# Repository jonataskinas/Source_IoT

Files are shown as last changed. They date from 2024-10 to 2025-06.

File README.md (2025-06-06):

# Source_IoT - V.01.00

Este repositório contém os arquivos de projeto da placa **Source_IoT V.01.00**, utilizada como ferramenta didática no curso **Projeto e Montagem de Placas de Circuito Impresso**.



## Sobre o Curso: Projeto e Montagem de Placas de Circuito Impresso

Este repositório reúne os arquivos do projeto **Source\_IoT - V.01.00**, desenvolvido como parte do curso *Projeto e Montagem de Placas de Circuito Impresso*. O curso tem como objetivo capacitar estudantes no **desenvolvimento, documentação, fabricação e montagem de placas de circuito impresso (PCBs)**.

Dividido em três módulos, o curso oferece uma jornada completa desde as boas práticas iniciais até a montagem física da placa:

### Módulo 1: Boas Práticas em Projetos de PCB

* Levantamento e especificação de requisitos para PCBs.
* Elaboração de representações arquiteturais e organização estrutural do projeto.
* Aplicação de boas práticas no fluxo de execução de projetos eletrônicos.

### Módulo 2: Projeto de uma Placa de Circuito Impresso

* Criação e organização do projeto em ambiente de CAD eletrônico.
* Construção de templates e bibliotecas de componentes.
* Elaboração de esquemáticos, roteamento e layout da PCB.
* Geração dos arquivos de manufatura e documentação final para produção.

### Módulo 3: Treinamento de Soldagem e Montagem

* Técnicas práticas de soldagem SMD e PTH.
* Procedimentos de montagem da placa projetada, garantindo qualidade e funcionalidade no produto final.

## Sobre a Placa: Source\_IoT - V.01.00

A **Source\_IoT - V.01.00** é uma placa didática projetada com foco em aplicações de Internet das Coisas (IoT), cuja ênfase principal está na **gestão de energia confiável a partir de múltiplas fontes de alimentação**, com mecanismos de proteção e suporte a bateria de backup.

A arquitetura da placa é composta por:

### 🔌 Fontes de Alimentação Múltiplas

* Entrada via **USB (5V)**
* Entrada externa via conector **VCC (12–24V)**
* Alimentação por **bateria Li-Ion ICR 14500 (3.7V - 700 mAh)** como fonte de backup

Essas entradas são gerenciadas com proteção contra tensão reversa e reguladas por um conversor buck (**AP63205**) e um conversor buck-boost (**RT6154AGQW**), garantindo estabilidade e segurança no fornecimento de energia para o microcontrolador **Raspberry Pi Pico W**.

### ⚡ Circuitos de Proteção

* **Proteção contra inversão de polaridade** nas entradas externas
* **Circuito de proteção da bateria**, baseado no comparador **TLV7031** e shunt **LM4041**, que monitora limites de tensão mínima e reinício da alimentação para preservar a integridade da célula

### 🔋 Gerenciamento da Carga da Bateria

* Utilização do carregador **MCP73831** (SOT-23-5), capaz de fornecer até **500 mA** para uma célula Li-Ion
* O circuito incorpora resistores de programação e indicadores de status de carga, assegurando operação segura e eficiente

### 🧠 Aplicação Principal

A placa foi concebida para ser integrada a sistemas embarcados com comunicação wireless e sensores externos, tendo como núcleo o **Raspberry Pi Pico W**. Seu objetivo é fornecer uma infraestrutura robusta para prototipagem e testes de soluções IoT com **continuidade de operação mesmo na ausência da fonte principal**.

## Organização dos Arquivos

Os arquivos do projeto estão organizados da seguinte forma:

### 📂 Altium Designer Sources

Na pasta `PCB_Project_Source_IoT` estão todos os arquivos fonte (`.PcbDoc`, `.SchDoc`, etc.) utilizados no design da PCB no Altium Designer.

### 🛠️ Fabrication and Assembly

Na subpasta `Project Outputs for PCB_Project_Source_IoT` (dentro da pasta do projeto `PCB_Project_Source_IoT`) estão os arquivos de fabricação (Gerbers, NC Drill), esquemáticos em PDF, lista de materiais (BOM - *Bill of Materials*) e outras informações essenciais para a fabricação e montagem da PCB.

## Como Utilizar este Repositório

### 📘 Para Estudo

Explore os esquemáticos e o layout da PCB na pasta descrita em **Altium Designer Sources** (requer Altium Designer) ou os PDFs em **Fabrication and Assembly**.

### 🏭 Para Fabricação

Utilize os arquivos da pasta **Fabrication and Assembly** para encomendar a fabricação da placa e adquirir os componentes listados na **BOM**.

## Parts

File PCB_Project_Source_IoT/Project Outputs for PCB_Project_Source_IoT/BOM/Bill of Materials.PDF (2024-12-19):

Projeto:
Arquivo:
Versão:
Data:
Contato:
Item | Quantity | Designator | Manufacturer Part Number | Description | Supplier 1 | Supplier Part Number 1 | Supplier Stock 1 | Supplier Unit Price 1 | Supplier Subtotal 1
1 | 4 | C1, C5, C7, C9 | CL21B104KACNNNC | CAP CER 0.1UF 25V
2 | 2 | C2, C3 | CL21A226MAYNNNE | CAP CER 22UF 25V
3 | 1 | C4 | CL31A106KBHNNNE | CAP CER 10UF 50V
4 | 2 | C6, C8 | C2012X5R1E475K125AB | CAP CER 4.7UF 25V
5 | 1 | CONN1 | TSW-101-07-G-D | CONN HEADER
6 | 5 | D1, D3, D7, D13, D14 | LTST-C170GKT | LED GREEN CLEAR
7 | 2 | D2, D15 | MMSZ5245B-TP | DIODE ZENER 15V
8 | 1 | D4 | SMBJ28CAQ-13-F | TVS DIODE 28VWM
9 | 5 | D5, D6, D10, D11, D12 | MBR120VLSFT1G | DIODE SCHOTTKY
10 | 1 | D8 | SMAJ5.0A-13-F | TVS DIODE 5VWM
11 | 1 | D9 | LTST-C171TBKT | LED BLUE CLEAR
12 | 1 | D16 | SMBJ6.0CA-TR | TVS DIODE 6VWM
13 | 4 | J1, J4, J5, J8 | 5447861 | TERM BLOCK PLUG
14 | 4 | J2, J3, J6, J7 | 5444262 | TERM BLOCK HDR 2POS 90DEG 3.81MM
15 | 1 | L1 | 1255AY-4R7M=P3 | FIXED IND 4.7UH
16 | 2 | R1, R8 | CRGCQ0805F100K | RES 100K OHM 1%
17 | 5 | R2, R6, R10, R14, R15 | CRGCQ0805J470R | RES 470 OHM 5%
18 | 3 | R3, R7, R16 | RC0805FR-0710KL | RES 10K OHM 1%
19 | 1 | R4 | RC0805FR-071KL | RES 1K OHM 1%
20 | 1 | R5 | ERJ-6ENF2001V | RES SMD 2K OHM
21 | 1 | R9 | RC0805FR-071ML | RES 1M OHM 1%
22 | 1 | R11 | RC0805FR-07270KL | RES 270K OHM 1%
23 | 1 | R12 | RC0805FR-0716KL | RES 16K OHM 1%
24 | 1 | R13 | RC0805FR-13330KL | RES 330K OHM 1%
25 | 2 | T1, T4 | DMP4065S-7 | MOSFET P-CH 40V
26 | 1 | T2 | DDTC143ZCA-7-F | TRANS PREBIAS NPN 200MW SOT23-3
27 | 1 | T3 | PJA3415_R1_00001 | MOSFET P-CHANNEL 20V 4A SOT23
28 | 1 | U1 | AP63205WU-7 | IC REGBUCK 5V 2A
29 | 1 | U2 | MCP73831T-2ACI/OT | IC BATT CNTL LI-
30 | 1 | U3 | TLV7031QDBVRQ1 | AUTOMOTIVE NANOPOWER COMPARATOR
31 | 1 | U4 | LM4041DYM3-1.2-TR | IC VREF SHUNT 1%
X7R 0805 | Digikey | 1276-1099-1-ND | 316661 | USD 0,02 | USD 0,15
X5R 0805 | Digikey | 1276-CL21A226MAYNNNECT-ND | 762600 | USD 0,20 | USD 0,40
X5R 1206 | DigiKey | 1276-2876-1-ND | 1075805 | USD 0,26 | USD 0,26
X5R 0805 | Digikey | 445-4116-1-ND | 2067686 | USD 0,27 | USD 0,54
VERT 2POS | Digikey | SAM1028-01-ND | 3311 | USD 0,51 | USD 0,51
SMD | Digikey | 160-1179-1-ND | 634631 | USD 0,24 | USD 1,20
500MW SOD123 | Digikey | MMSZ5245B-TPMSCT-ND | 598438 | USD 0,10 | USD 0,20
45.4VC SMB | Digikey | SMBJ28CAQ-13-FDICT-ND | 70239 | USD 0,29 | USD 0,29
20V 1A SOD123FL | Digikey | MBR120VLSFT1GOSCT-ND | 35869 | USD 0,41 | USD 2,05
9.2VC SMA | Digikey | SMAJ5.0A-E3/61GICT-ND | 377044 | USD 0,22 | USD 0,22
CHIP SMD | Digikey | 160-1645-1-ND | 28721 | USD 0,32 | USD 0,32
10.3VC SMB | Digikey | 497-7454-1-ND | 3849 | USD 0,47 | USD 0,47
2POS STR 3.81MM | Digikey | 277-11343-ND | 112391 | USD 1,34 | USD 5,36
Digikey | 277-11313-ND | 196691 | USD 0,70 | USD 2,80
4A 23 MOHM SMD | Digikey | 587-2969-1-ND | 1742 | USD 0,42 | USD 0,42
1/8W 0805 | Digikey | A129773CT-ND | 237957 | USD 0,10 | USD 0,20
1/8W 0805 | Digikey | A130132CT-ND | 807068 | USD 0,03 | USD 0,27
1/8W 0805 | Digikey | 541-3976-1-ND | 1544810 | USD 0,10 | USD 0,30
1/8W 0805 | Digikey | 311-1.00KCRCT-ND | 1414483 | USD 0,10 | USD 0,10
1%1/8W 0805 | DigiKey | P2.00KCCT-ND | 132054 | USD 0,11 | USD 0,11
1/8W 0805 | Digikey | 311-1.00MCRCT-ND | 192975 | USD 0,10 | USD 0,10
1/8W 0805 | Digikey | P270KCCT-ND | 57015 | USD 0,11 | USD 0,11
1/8W 0805 | Digikey | 311-16.0KCRCT-ND | 149107 | USD 0,10 | USD 0,10
1/8W 0805 | Digikey | 13-RC0805FR-13330KLCT-ND | 22156 | USD 0,10 | USD 0,10
2.4A SOT23 | Digikey | DMP4065S-7DICT-ND | 31505 | USD 0,32 | USD 0,64
Digikey | 1727-3045-1-ND | 11441 | USD 0,10 | USD 0,10
Digikey | 3757-PJA3415_R1_00001CT-ND | 6943 | USD 0,33 | USD 0,33
TSOT23-6 | Digikey | AP63205WU-7DICT-ND | 29947 | USD 1,32 | USD 1,32
ION 1CEL SOT23-5 | Digikey | MCP73831T-2ACI/OTCT-ND | 92319 | USD 0,76 | USD 0,76
Digikey | 296-TLV7031QDBVRQ1CT-ND | 15246 | USD 0,72 | USD 0,72
SOT23-3 | Digikey | 576-2572-1-ND | 39272 | USD 0,36 | USD 0,36

### 59 USD 20,81

# Lista de Materiais

22/11/2024

v.0.1

PCB_Project_Source_IoT.BomDoc

Virtus CC

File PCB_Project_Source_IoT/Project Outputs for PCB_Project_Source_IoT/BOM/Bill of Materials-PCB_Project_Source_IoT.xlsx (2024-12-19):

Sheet: BoM
Lista de Materiais
Projeto: | Virtus CC
Arquivo: | PCB_Project_Source_IoT.BomDoc
Versão: | v.0.1
Data: | 22/11/2024
Contato:
Item | Quantity | Designator | Manufacturer Part Number | Description | Supplier 1 | Supplier Part Number 1 | Supplier Stock 1 | Supplier Unit Price 1 | Supplier Subtotal 1
1 | 4 | C1, C5, C7, C9 | CL21B104KACNNNC | CAP CER 0.1UF 25V X7R 0805 | Digikey | 1276-1099-1-ND | 316661 | USD 0.01 | USD 0.15
2 | 2 | C2, C3 | CL21A226MAYNNNE | CAP CER 22UF 25V X5R 0805 | Digikey | 1276-CL21A226MAYNNNECT-ND | 762600 | USD 0.20 | USD 0.40
3 | 1 | C4 | CL31A106KBHNNNE | CAP CER 10UF 50V X5R 1206 | DigiKey | 1276-2876-1-ND | 1075805 | USD 0.26 | USD 0.26
4 | 2 | C6, C8 | C2012X5R1E475K125AB | CAP CER 4.7UF 25V X5R 0805 | Digikey | 445-4116-1-ND | 2067686 | USD 0.27 | USD 0.54
5 | 1 | CONN1 | TSW-101-07-G-D | CONN HEADER VERT 2POS | Digikey | SAM1028-01-ND | 3311 | USD 0.51 | USD 0.51
6 | 5 | D1, D3, D7, D13, D14 | LTST-C170GKT | LED GREEN CLEAR SMD | Digikey | 160-1179-1-ND | 634631 | USD 0.24 | USD 1.20
7 | 2 | D2, D15 | MMSZ5245B-TP | DIODE ZENER 15V 500MW SOD123 | Digikey | MMSZ5245B-TPMSCT-ND | 598438 | USD 0.10 | USD 0.20
8 | 1 | D4 | SMBJ28CAQ-13-F | TVS DIODE 28VWM 45.4VC SMB | Digikey | SMBJ28CAQ-13-FDICT-ND | 70239 | USD 0.29 | USD 0.29
9 | 5 | D5, D6, D10, D11, D12 | MBR120VLSFT1G | DIODE SCHOTTKY 20V 1A SOD123FL | Digikey | MBR120VLSFT1GOSCT-ND | 35869 | USD 0.41 | USD 2.05
10 | 1 | D8 | SMAJ5.0A-13-F | TVS DIODE 5VWM 9.2VC SMA | Digikey | SMAJ5.0A-E3/61GICT-ND | 377044 | USD 0.22 | USD 0.22
11 | 1 | D9 | LTST-C171TBKT | LED BLUE CLEAR CHIP SMD | Digikey | 160-1645-1-ND | 28721 | USD 0.32 | USD 0.32
12 | 1 | D16 | SMBJ6.0CA-TR | TVS DIODE 6VWM 10.3VC SMB | Digikey | 497-7454-1-ND | 3849 | USD 0.47 | USD 0.47
13 | 4 | J1, J4, J5, J8 | 5447861 | TERM BLOCK PLUG 2POS STR 3.81MM | Digikey | 277-11343-ND | 112391 | USD 1.34 | USD 5.36
14 | 4 | J2, J3, J6, J7 | 5444262 | TERM BLOCK HDR 2POS 90DEG 3.81MM | Digikey | 277-11313-ND | 196691 | USD 0.70 | USD 2.80
15 | 1 | L1 | 1255AY-4R7M=P3 | FIXED IND 4.7UH 4A 23 MOHM SMD | Digikey | 587-2969-1-ND | 1742 | USD 0.42 | USD 0.42
16 | 2 | R1, R8 | CRGCQ0805F100K | RES 100K OHM 1% 1/8W 0805 | Digikey | A129773CT-ND | 237957 | USD 0.10 | USD 0.20
17 | 5 | R2, R6, R10, R14, R15 | CRGCQ0805J470R | RES 470 OHM 5% 1/8W 0805 | Digikey | A130132CT-ND | 807068 | USD 0.03 | USD 0.27
18 | 3 | R3, R7, R16 | RC0805FR-0710KL | RES 10K OHM 1% 1/8W 0805 | Digikey | 541-3976-1-ND | 1544810 | USD 0.10 | USD 0.30
19 | 1 | R4 | RC0805FR-071KL | RES 1K OHM 1% 1/8W 0805 | Digikey | 311-1.00KCRCT-ND | 1414483 | USD 0.10 | USD 0.10
20 | 1 | R5 | ERJ-6ENF2001V | RES SMD 2K OHM 1% 1/8W 0805 | DigiKey | P2.00KCCT-ND | 132054 | USD 0.11 | USD 0.11
21 | 1 | R9 | RC0805FR-071ML | RES 1M OHM 1% 1/8W 0805 | Digikey | 311-1.00MCRCT-ND | 192975 | USD 0.10 | USD 0.10
22 | 1 | R11 | RC0805FR-07270KL | RES 270K OHM 1% 1/8W 0805 | Digikey | P270KCCT-ND | 57015 | USD 0.11 | USD 0.11
23 | 1 | R12 | RC0805FR-0716KL | RES 16K OHM 1% 1/8W 0805 | Digikey | 311-16.0KCRCT-ND | 149107 | USD 0.10 | USD 0.10
24 | 1 | R13 | RC0805FR-13330KL | RES 330K OHM 1% 1/8W 0805 | Digikey | 13-RC0805FR-13330KLCT-ND | 22156 | USD 0.10 | USD 0.10
25 | 2 | T1, T4 | DMP4065S-7 | MOSFET P-CH 40V 2.4A SOT23 | Digikey | DMP4065S-7DICT-ND | 31505 | USD 0.32 | USD 0.64
26 | 1 | T2 | DDTC143ZCA-7-F | TRANS PREBIAS NPN 200MW SOT23-3 | Digikey | 1727-3045-1-ND | 11441 | USD 0.10 | USD 0.10
27 | 1 | T3 | PJA3415_R1_00001 | MOSFET P-CHANNEL 20V 4A SOT23 | Digikey | 3757-PJA3415_R1_00001CT-ND | 6943 | USD 0.33 | USD 0.33
28 | 1 | U1 | AP63205WU-7 | IC REG BUCK 5V 2A TSOT23-6 | Digikey | AP63205WU-7DICT-ND | 29947 | USD 1.32 | USD 1.32
29 | 1 | U2 | MCP73831T-2ACI/OT | IC BATT CNTL LI-ION 1CEL SOT23-5 | Digikey | MCP73831T-2ACI/OTCT-ND | 92319 | USD 0.76 | USD 0.76
30 | 1 | U3 | TLV7031QDBVRQ1 | AUTOMOTIVE NANO POWER COMPARATOR | Digikey | 296-TLV7031QDBVRQ1CT-ND | 15246 | USD 0.72 | USD 0.72
31 | 1 | U4 | LM4041DYM3-1.2-TR | IC VREF SHUNT 1% SOT23-3 | Digikey | 576-2572-1-ND | 39272 | USD 0.36 | USD 0.36
 | 59 |  |  |  |  |  |  |  | USD 20.81

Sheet: Impostos
Impostos
 | Valores
 | Valor (USD) | Valor (BRL)
Valor do produto | USD 20.81 | BRL 117.30
Valor do frete | USD 40.00 | BRL 225.47
Imposto alfandegário (60%) | USD 36.49 | BRL 205.66
ICMS Paraíba (18%) | USD 21.36 | BRL 120.39
Taxa de Desembaraço FEDEX | USD 16.87 | BRL 95.09
Total | USD 74.71 | BRL 421.15
Valor a Pagar
USD <-> BRL (22/11/24) | 5.42
Spread do dólar (4%) | 5.64
 | Valores
Pagamento 01 | USD 60.81 | BRL 342.77
Pagamento 02 | USD 74.71 | BRL 421.15
Valor total da compra | USD 135.52 | BRL 763.92
Pagamento 01 é realizado no ato da compra, cobrado imediatamente no cartão de crédito.
Pagamento 02 é realizado no ato da recepção da mercadoria, cobrado pelo courrier referente às despesas aduaneiras e de desembaraço.

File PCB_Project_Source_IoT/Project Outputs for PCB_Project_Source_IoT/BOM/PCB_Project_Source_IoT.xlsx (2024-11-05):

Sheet: BoM
Lista de Materiais
Projeto: | Virtus CC
Arquivo: | PCB_Project_Source_IoT.BomDoc
Versão: | v.0.1
Data: | 17/10/2024
Contato:
Item | Quantity | Designator | Manufacturer Part Number | Description | Supplier 1 | Supplier Part Number 1 | Supplier Stock 1 | Supplier Unit Price 1 | Supplier Subtotal 1
1 | 4 | C1, C5, C7, C9 | CL21B104KACNNNC | CAP CER 0.1UF 25V X7R 0805 | Digikey | 1276-1099-1-ND | 264937 | USD 0.03 | USD 0.31
2 | 2 | C2, C3 | CL21A226MAYNNNE | CAP CER 22UF 25V X5R 0805 | Digikey | 1276-CL21A226MAYNNNECT-ND | 307548 | USD 0.26 | USD 0.52
3 | 1 | C4 | CL31A106KBHNNNE | CAP CER 10UF 50V X5R 1206 | DigiKey | 1276-2876-1-ND | 1144400 | USD 0.36 | USD 0.36
4 | 2 | C6, C8 | C2012X5R1E475K125AB | CAP CER 4.7UF 25V X5R 0805 | Digikey | 445-4116-1-ND | 2079251 | USD 0.27 | USD 0.54
5 | 1 | CONN1 | TSW-101-07-G-D | CONN HEADER VERT 2POS | Digikey | SAM1028-01-ND | 1995 | USD 0.30 | USD 0.30
6 | 5 | D1, D3, D7, D13, D14 | LTST-C170GKT | LED GREEN CLEAR SMD | Digikey | 160-1179-1-ND | 683154 | USD 0.24 | USD 1.20
7 | 2 | D2, D15 | MMSZ5245B-TP | DIODE ZENER 15V 500MW SOD123 | Digikey | MMSZ5245B-TPMSCT-ND | 603045 | USD 0.10 | USD 0.20
8 | 1 | D4 | SMBJ28CAQ-13-F | TVS DIODE 28VWM 45.4VC SMB | Digikey | SMBJ28CAQ-13-FDICT-ND | 70506 | USD 0.49 | USD 0.49
9 | 5 | D5, D6, D10, D11, D12 | MBR120VLSFT1G | DIODE SCHOTTKY 20V 1A SOD123FL | Digikey | MBR120VLSFT1GOSCT-ND | 7907 | USD 0.41 | USD 2.05
10 | 1 | D8 | SMAJ5.0A-13-F | TVS DIODE 5VWM 9.2VC SMA | Digikey | SMAJ5.0A-E3/61GICT-ND | 375312 | USD 0.32 | USD 0.32
11 | 1 | D9 | LTST-C171TBKT | LED BLUE CLEAR CHIP SMD | Digikey | 160-1645-1-ND | 37476 | USD 0.32 | USD 0.32
12 | 1 | D16 | SMBJ6.0CA-TR | TVS DIODE 6VWM 10.3VC SMB | Digikey | 497-7454-1-ND | 7168 | USD 0.47 | USD 0.47
13 | 4 | J1, J4, J5, J8 | 5447861 | TERM BLOCK PLUG 2POS STR 3.81MM | Digikey | 277-11343-ND | 112737 | USD 1.34 | USD 5.36
14 | 4 | J2, J3, J6, J7 | 5444262 | TERM BLOCK HDR 2POS 90DEG 3.81MM | Digikey | 277-11313-ND | 197979 | USD 0.70 | USD 2.80
15 | 1 | L1 | 1255AY-4R7M=P3 | FIXED IND 4.7UH 4A 23 MOHM SMD | Digikey | 587-2969-1-ND | 7939 | USD 0.42 | USD 0.42
16 | 2 | R1, R8 | CRGCQ0805F100K | RES 100K OHM 1% 1/8W 0805 | Digikey | A129773CT-ND | 238397 | USD 0.10 | USD 0.20
17 | 5 | R2, R6, R10, R14, R15 | CRGCQ0805J470R | RES 470 OHM 5% 1/8W 0805 | Digikey | A130132CT-ND | 816282 | USD 0.03 | USD 0.27
18 | 3 | R3, R7, R16 | RC0805FR-0710KL | RES 10K OHM 1% 1/8W 0805 | Digikey | 311-10.0KCRCT-ND | 212921 | USD 0.02 | USD 0.17
19 | 1 | R4 | RC0805FR-071KL | RES 1K OHM 1% 1/8W 0805 | Digikey | 311-1.00KCRCT-ND | 1656654 | USD 0.10 | USD 0.10
20 | 1 | R5 | ERJ-6ENF2001V | RES SMD 2K OHM 1% 1/8W 0805 | Digikey | P2.00KCCT-ND | 164204 | USD 0.11 | USD 0.11
21 | 1 | R9 | RC0805FR-071ML | RES 1M OHM 1% 1/8W 0805 | Digikey | 311-1.00MCRCT-ND | 150822 | USD 0.10 | USD 0.10
22 | 1 | R11 | RC0805FR-07270KL | RES 270K OHM 1% 1/8W 0805 | Digikey | 311-270KCRCT-ND | 1252 | USD 0.10 | USD 0.10
23 | 1 | R12 | RC0805FR-0716KL | RES 16K OHM 1% 1/8W 0805 | Digikey | 311-16.0KCRCT-ND | 156943 | USD 0.10 | USD 0.10
24 | 1 | R13 | RC0805FR-13330KL | RES 330K OHM 1% 1/8W 0805 | Digikey | 13-RC0805FR-13330KLCT-ND | 22171 | USD 0.10 | USD 0.10
25 | 2 | T1, T4 | DMP4065S-7 | MOSFET P-CH 40V 2.4A SOT23 | Digikey | DMP4065S-7DICT-ND | 35173 | USD 0.32 | USD 0.64
26 | 1 | T2 | DDTC143ZCA-7-F | TRANS PREBIAS NPN 200MW SOT23-3 | Digikey | 1727-3045-1-ND | 181541 | USD 0.10 | USD 0.10
27 | 1 | T3 | PJA3415_R1_00001 | MOSFET P-CHANNEL 20V 4A SOT23 | Digikey | 3757-PJA3415_R1_00001CT-ND | 6968 | USD 0.23 | USD 0.23
28 | 1 | U1 | AP63205WU-7 | IC REG BUCK 5V 2A TSOT23-6 | Digikey | AP63205WU-7DICT-ND | 19687 | USD 1.32 | USD 1.32
29 | 1 | U2 | MCP73831T-2ACI/OT | IC BATT CNTL LI-ION 1CEL SOT23-5 | Digikey | MCP73831T-2ACI/OTCT-ND | 98382 | USD 0.76 | USD 0.76
30 | 1 | U3 | TLV7031QDBVRQ1 | AUTOMOTIVE NANO POWER COMPARATOR | Digikey | 296-TLV7031QDBVRQ1CT-ND | 15558 | USD 0.82 | USD 0.82
31 | 1 | U4 | LM4041DYM3-1.2-TR | IC VREF SHUNT 1% SOT23-3 | Digikey | 576-2572-1-ND | 40315 | USD 0.36 | USD 0.36
 | 59 |  |  |  |  |  |  |  | USD 21.14

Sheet: Impostos
Impostos
 | Valores
 | Valor (USD) | Valor (BRL)
Valor do produto | USD 21.14 | BRL 119.16
Valor do frete | USD 40.00 | BRL 225.47
Imposto alfandegário (60%) | USD 36.68 | BRL 206.78
ICMS Paraíba (18%) | USD 21.47 | BRL 121.04
Taxa de Desembaraço FEDEX | USD 16.87 | BRL 95.09
Total | USD 75.03 | BRL 422.92
Valor a Pagar
USD <-> BRL (17/10/24) | 5.42
Spread do dólar (4%) | 5.64
 | Valores
Pagamento 01 | USD 61.14 | BRL 344.63
Pagamento 02 | USD 75.03 | BRL 422.92
Valor total da compra | USD 136.17 | BRL 767.55
Pagamento 01 é realizado no ato da compra, cobrado imediatamente no cartão de crédito.
Pagamento 02 é realizado no ato da recepção da mercadoria, cobrado pelo courrier referente às despesas aduaneiras e de desembaraço.

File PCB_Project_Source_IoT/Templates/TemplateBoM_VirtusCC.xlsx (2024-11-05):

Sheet: BoM
Lista de Materiais
Projeto: | Field = Projeto
Arquivo: | Field = DataSourceFileName
Versão: | Field = Rev
Data: | Field = ReportDate
Contato:
Item | Column=Quantity | Column=Designator | Column=Manufacturer Part Number | Column=Description | Column=Supplier 1 | Column=Supplier Part Number 1 | Column=Supplier Stock 1 | Column=Supplier Unit Price 1 | Column=Supplier Subtotal 1
1
2
3
 | 0 |  |  |  |  |  |  |  | USD 0.00

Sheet: Impostos
Impostos
 | Valores
 | Valor (USD) | Valor (BRL)
Valor do produto | USD 0.00 | BRL 0.00
Valor do frete | USD 40.00 | BRL 225.47
Imposto alfandegário (60%) | USD 24.00 | BRL 135.28
ICMS Paraíba (18%) | USD 14.05 | BRL 79.19
Taxa de Desembaraço FEDEX | USD 16.87 | BRL 95.09
Total | USD 54.92 | BRL 309.57
Valor a Pagar
USD <-> BRL (06/10/24) | 5.42
Spread do dólar (4%) | 5.64
 | Valores
Pagamento 01 | USD 40.00 | BRL 225.47
Pagamento 02 | USD 54.92 | BRL 309.57
Valor total da compra | USD 94.92 | BRL 535.04
Pagamento 01 é realizado no ato da compra, cobrado imediatamente no cartão de crédito.
Pagamento 02 é realizado no ato da recepção da mercadoria, cobrado pelo courrier referente às despesas aduaneiras e de desembaraço.

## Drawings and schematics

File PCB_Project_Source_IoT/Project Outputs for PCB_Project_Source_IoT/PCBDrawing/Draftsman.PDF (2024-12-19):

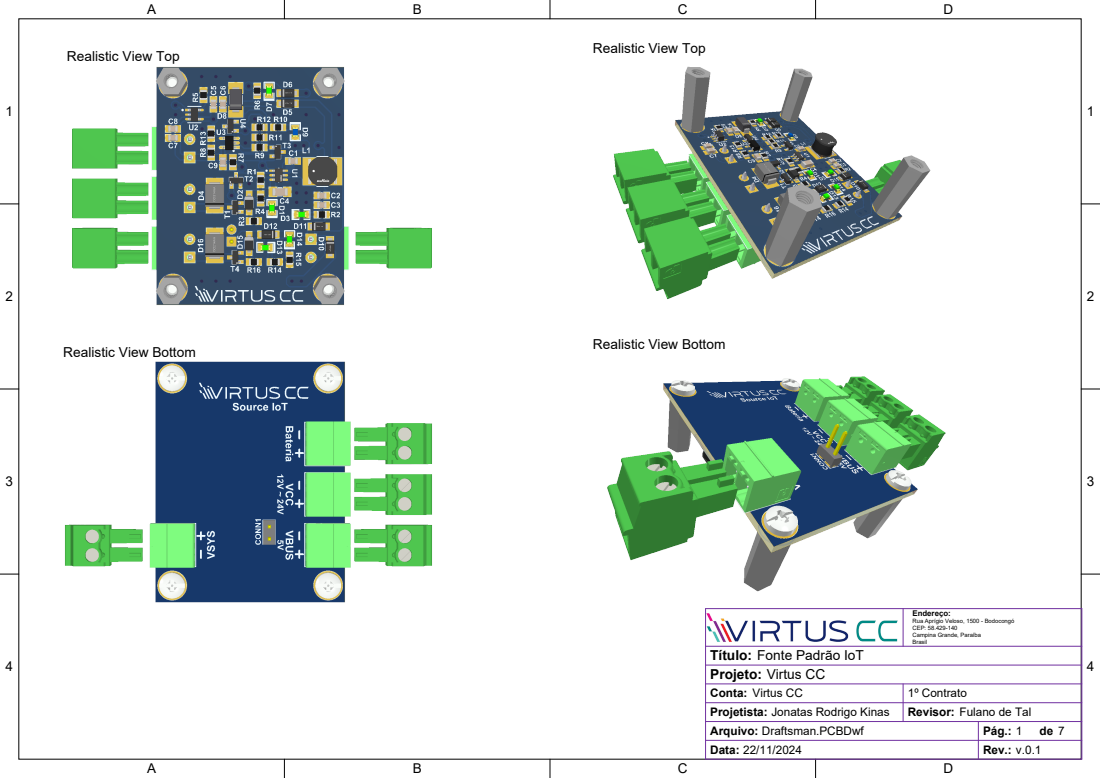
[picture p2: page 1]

Endereço:
Rua Aprígio Veloso, 1500 - Bodocongó
CEP: 58.429-140
Campina Grande, Paraíba
Brasil

Conta: Virtus CC | 1º Contrato
Projetista: Jonatas Rodrigo Kinas | Revisor: Fulano de Tal
Arquivo: Draftsman.PCBDwf | Pág.: de
Data: | Rev.: v.0.1

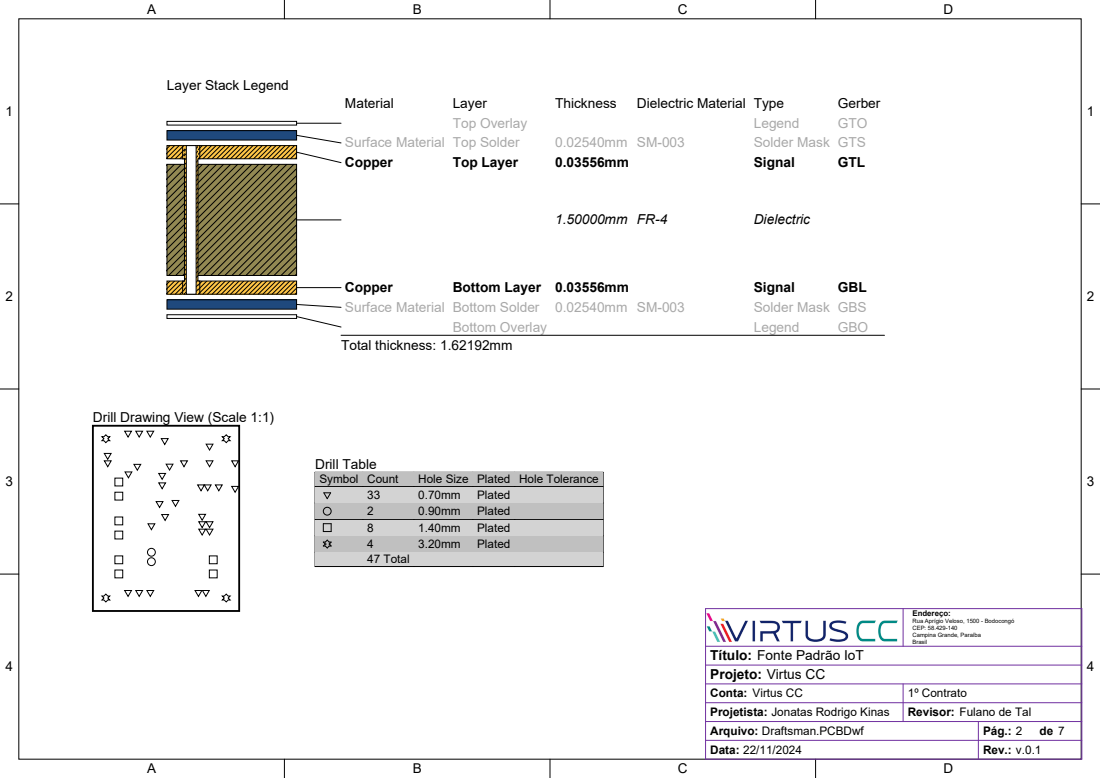
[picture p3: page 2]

Drill Drawing View (Scale 1:1)

Symbol | Count | Hole Size | Plated | Hole Tolerance

33 | 0.70mm | Plated
2 | 0.90mm | Plated
8 | 1.40mm | Plated
4 | 3.20mm | Plated
47 Total

Endereço:
Rua Aprígio Veloso, 1500 - Bodocongó
CEP: 58.429-140
Campina Grande, Paraíba
Brasil

Conta: Virtus CC | 1º Contrato
Projetista: Jonatas Rodrigo Kinas | Revisor: Fulano de Tal

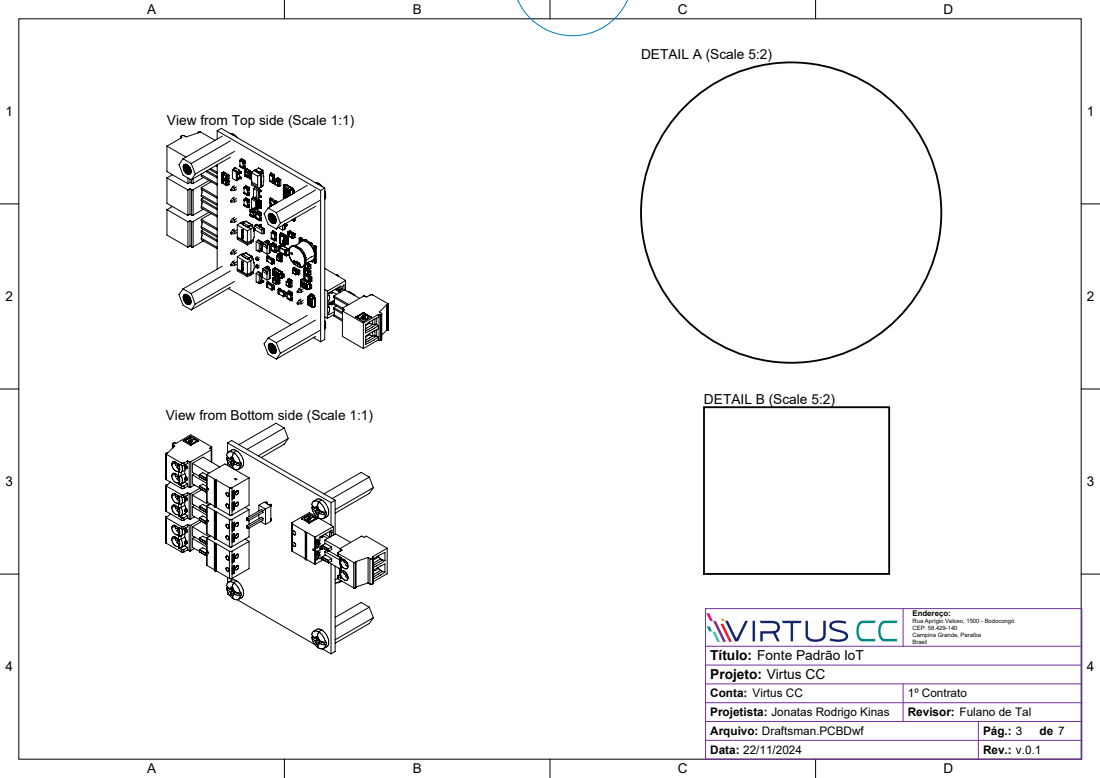
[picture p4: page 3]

View from Top side (Scale 1:1)

View from Bottom side (Scale 1:1)

Endereço:
Rua Aprígio Veloso, 1500 - Bodocongó
CEP: 58.429-140
Campina Grande, Paraíba
Brasil

Conta: Virtus CC | 1º Contrato
Projetista: Jonatas Rodrigo Kinas | Revisor: Fulano de Tal

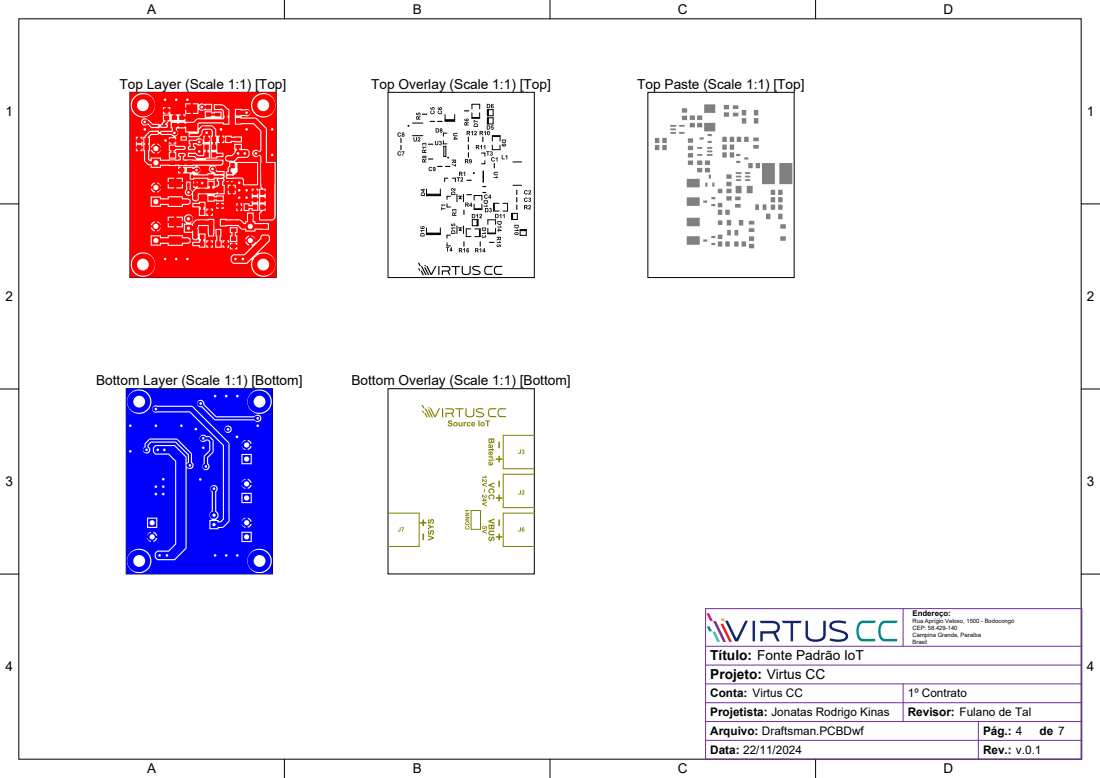
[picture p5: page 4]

Top Layer (Scale 1:1) [Top]

Top Overlay (Scale 1:1) [Top]

Top Paste (Scale 1:1) [Top]

Bottom Layer (Scale 1:1) [Bottom]

Bottom Overlay (Scale 1:1) [Bottom]

Endereço:
Rua Aprígio Veloso, 1500 - Bodocongó
CEP: 58.429-140
Campina Grande, Paraíba
Brasil

Conta: Virtus CC | 1º Contrato
Projetista: Jonatas Rodrigo Kinas | Revisor: Fulano de Tal

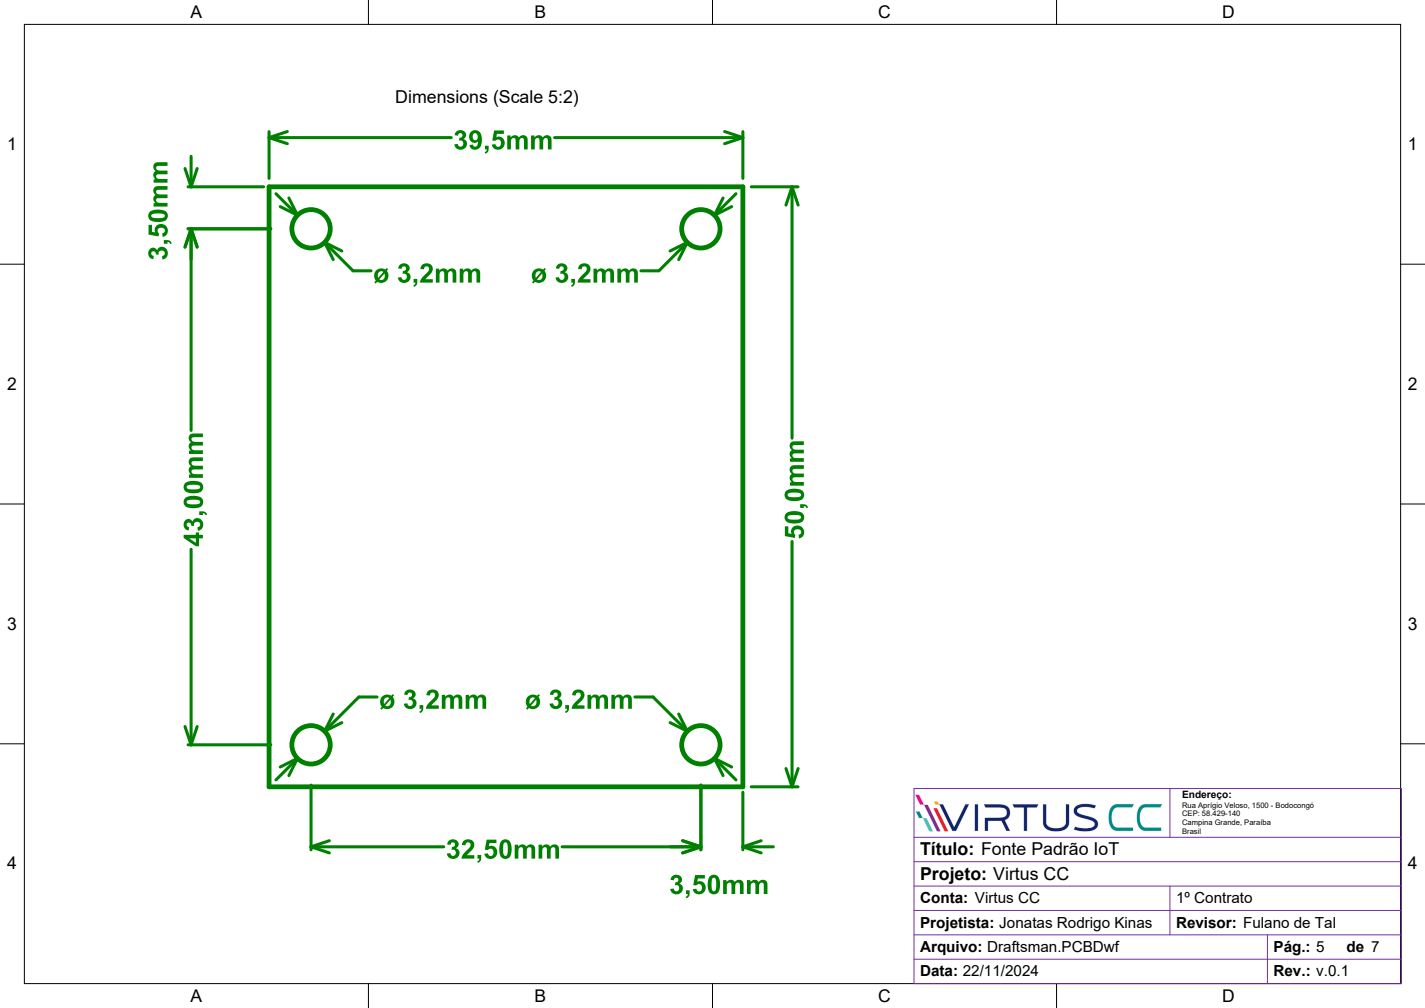
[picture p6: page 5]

Endereço:
Rua Aprígio Veloso, 1500 - Bodocongó
CEP: 58.429-140
Campina Grande, Paraíba
Brasil

Conta: Virtus CC | 1º Contrato
Projetista: Jonatas Rodrigo Kinas | Revisor: Fulano de Tal

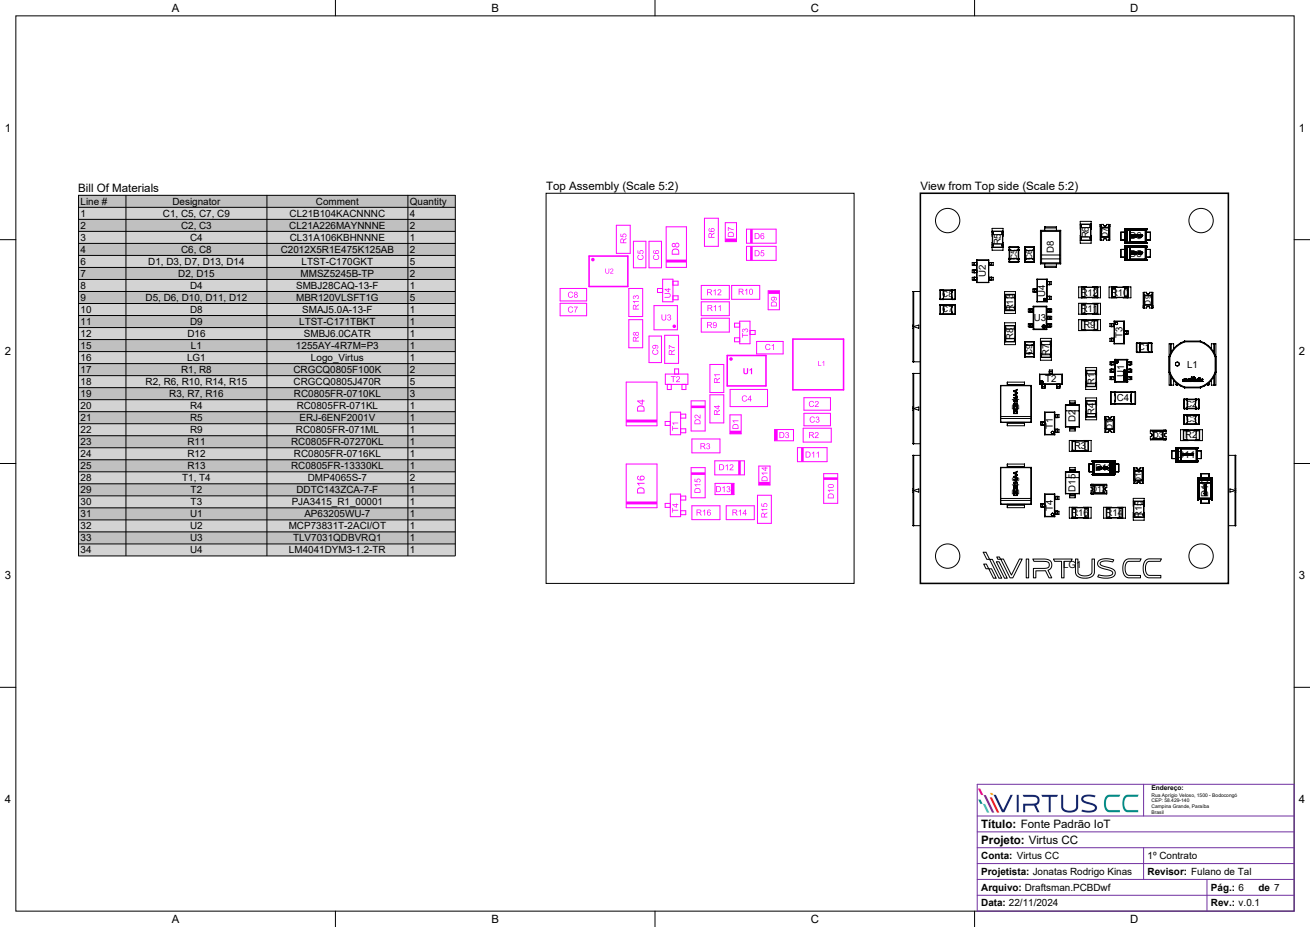
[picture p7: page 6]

1 | C1, C5, C7, C9 | CL21B104KACNNNC | 4
2 | C2, C3 | CL21A226MAYNNNE | 2
3 | C4 | CL31A106KBHNNNE | 1
4 | C6, C8 | C2012X5R1E475K125AB | 2
6 | D1, D3, D7, D13, D14 | LTST-C170GKT | 5
7 | D2, D15 | MMSZ5245B-TP | 2
8 | D4 | SMBJ28CAQ-13-F | 1
9 | D5, D6, D10, D11, D12 | MBR120VLSFT1G | 5

11 | D9 | LTST-C171TBKT | 1
12 | D16 | SMBJ6.0CATR | 1
15 | L1 | 1255AY-4R7M=P3 | 1
16 | LG1 | Logo_Virtus | 1
17 | R1, R8 | CRGCQ0805F100K | 2
18 | R2, R6, R10, R14, R15 | CRGCQ0805J470R | 5
19 | R3, R7, R16 | RC0805FR-0710KL | 3
20 | R4 | RC0805FR-071KL | 1
21 | R5 | ERJ-6ENF2001V | 1
22 | R9 | RC0805FR-071ML | 1
23 | R11 | RC0805FR-07270KL | 1
24 | R12 | RC0805FR-0716KL | 1
25 | R13 | RC0805FR-13330KL | 1
28 | T1, T4 | DMP4065S-7 | 2
29 | T2 | DDTC143ZCA-7-F | 1
30 | T3 | PJA3415_R1_00001 | 1

33 | U3 | TLV7031QDBVRQ1 | 1
34 | U4 | LM4041DYM3-1.2-TR | 1

Endereço:
Rua Aprígio Veloso, 1500 - Bodocongó
CEP: 58.429-140
Campina Grande, Paraíba
Brasil

Conta: Virtus CC | 1º Contrato
Projetista: Jonatas Rodrigo Kinas | Revisor: Fulano de Tal

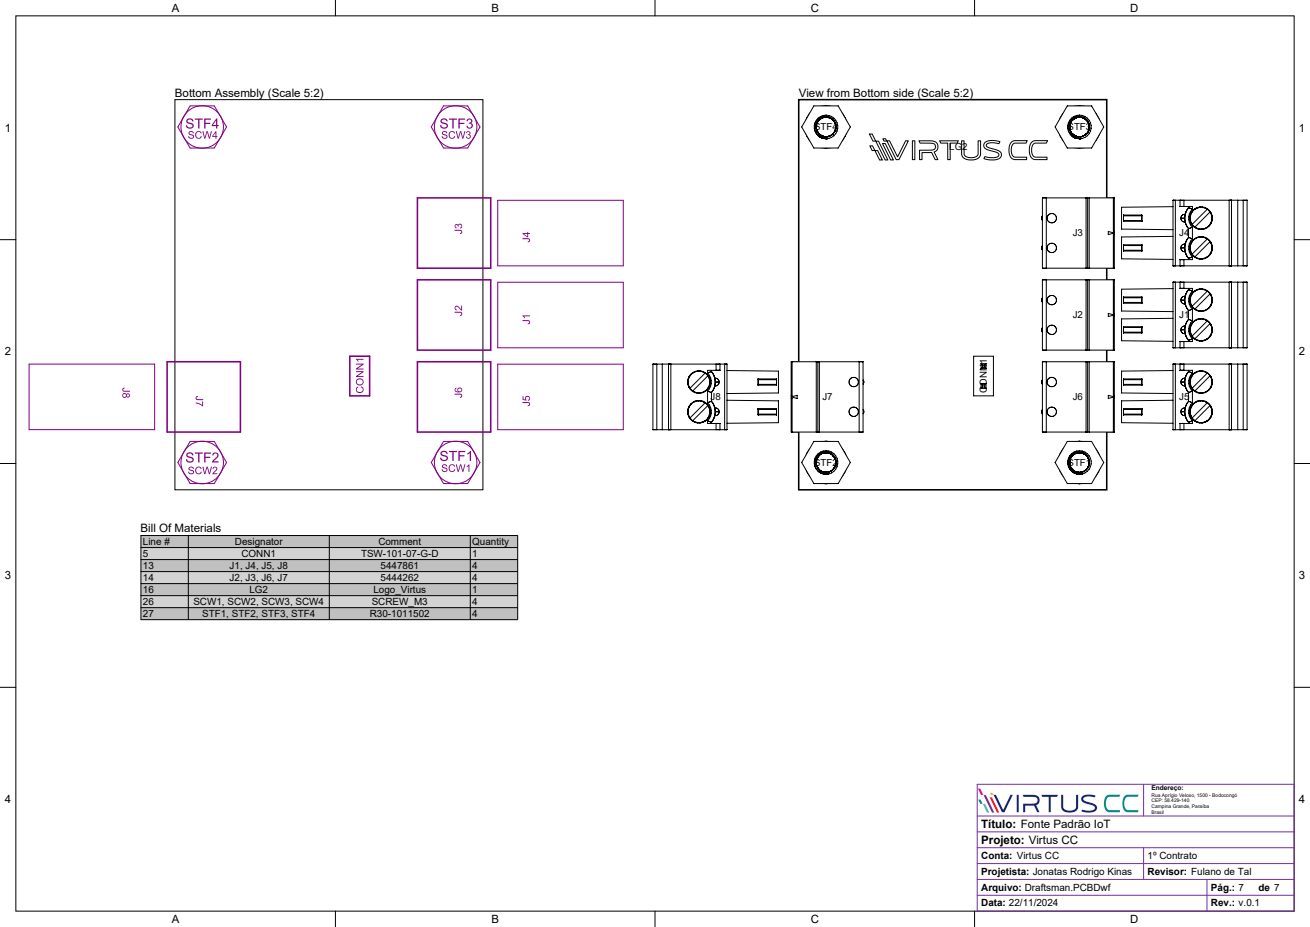
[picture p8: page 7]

View from Bottom side (Scale 5:2)

Line # | Designator | Comment | Quantity
5 | CONN1 | TSW-101-07-G-D | 1
13 | J1, J4, J5, J8 | 5447861 | 4
14 | J2, J3, J6, J7 | 5444262 | 4
16 | LG2 | Logo_Virtus | 1
26 | SCW1, SCW2, SCW3, SCW4 | SCREW_M3 | 4
27 | STF1, STF2, STF3, STF4 | R30-1011502 | 4

Endereço:
Rua Aprígio Veloso, 1500 - Bodocongó
CEP: 58.429-140
Campina Grande, Paraíba
Brasil

Conta: Virtus CC | 1º Contrato
Projetista: Jonatas Rodrigo Kinas | Revisor: Fulano de Tal

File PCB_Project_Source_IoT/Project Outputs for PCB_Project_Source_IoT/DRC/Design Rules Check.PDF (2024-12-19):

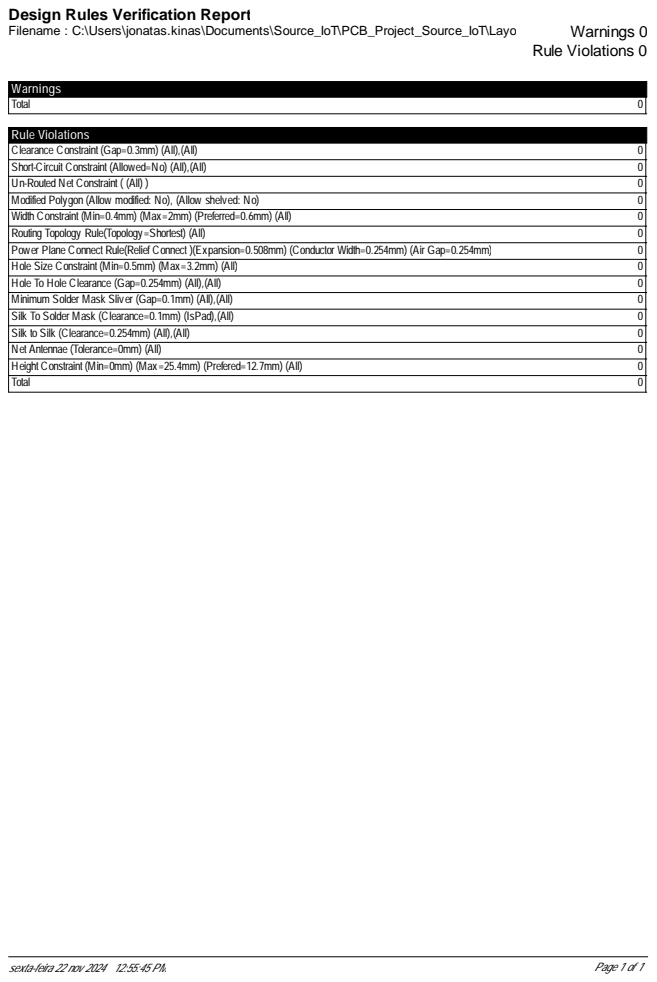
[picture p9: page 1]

Design Rules Verification Report

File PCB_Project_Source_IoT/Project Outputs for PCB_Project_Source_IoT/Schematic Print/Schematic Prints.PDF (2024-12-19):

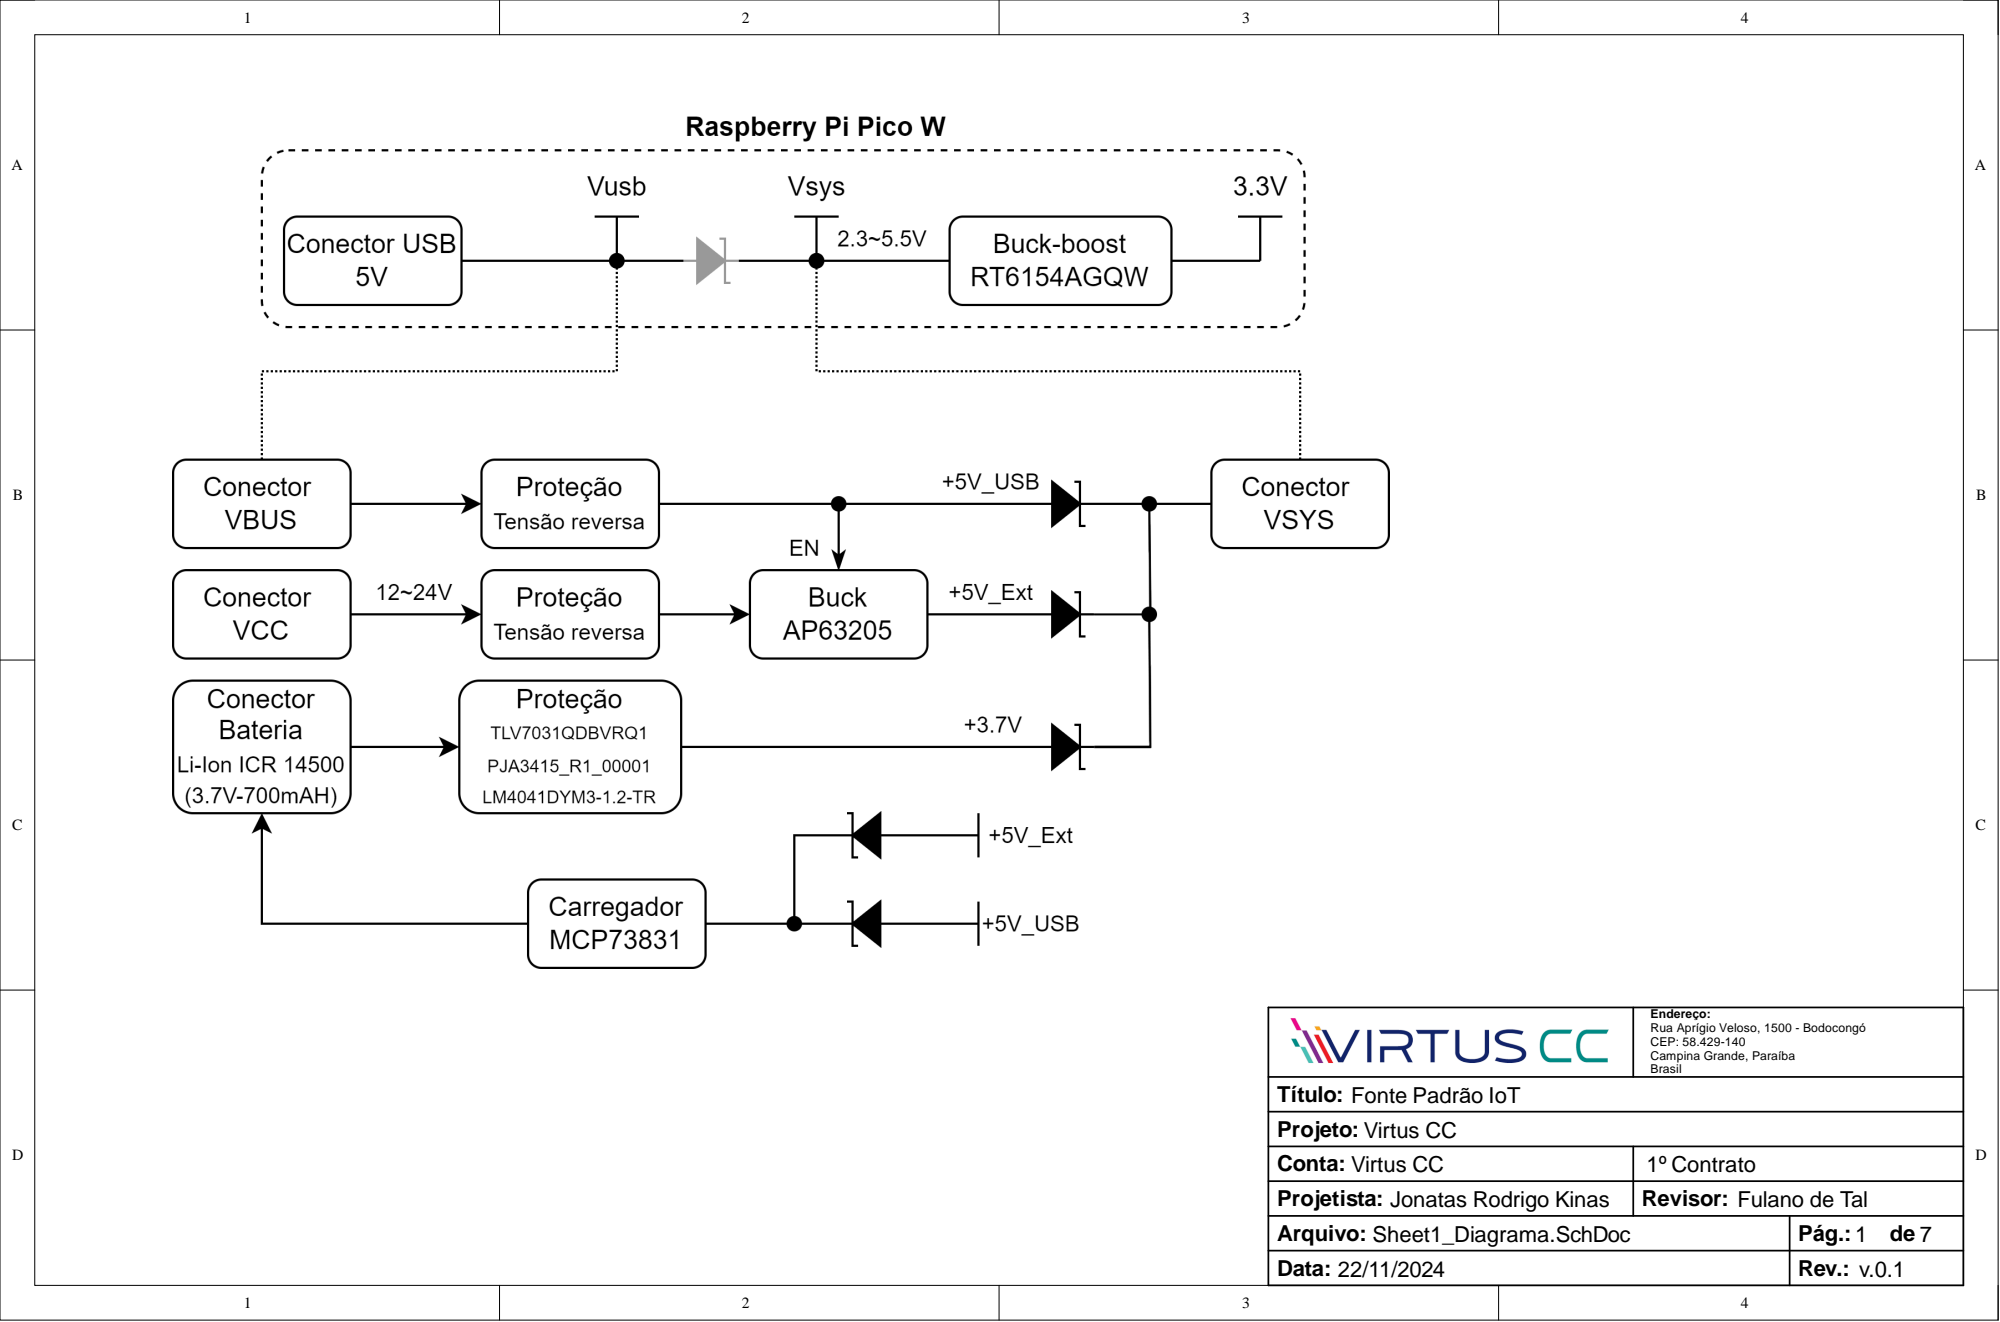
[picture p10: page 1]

Endereço:
Rua Aprígio Veloso, 1500 - Bodocongó
CEP: 58.429-140
Campina Grande, Paraíba
Brasil

Conta: Virtus CC | 1º Contrato
Projetista: Jonatas Rodrigo Kinas | Revisor: Fulano de Tal
Arquivo: Sheet1_Diagrama.SchDoc | Pág.: 1 de 7
Data: 22/11/2024 | Rev.: v.0.1

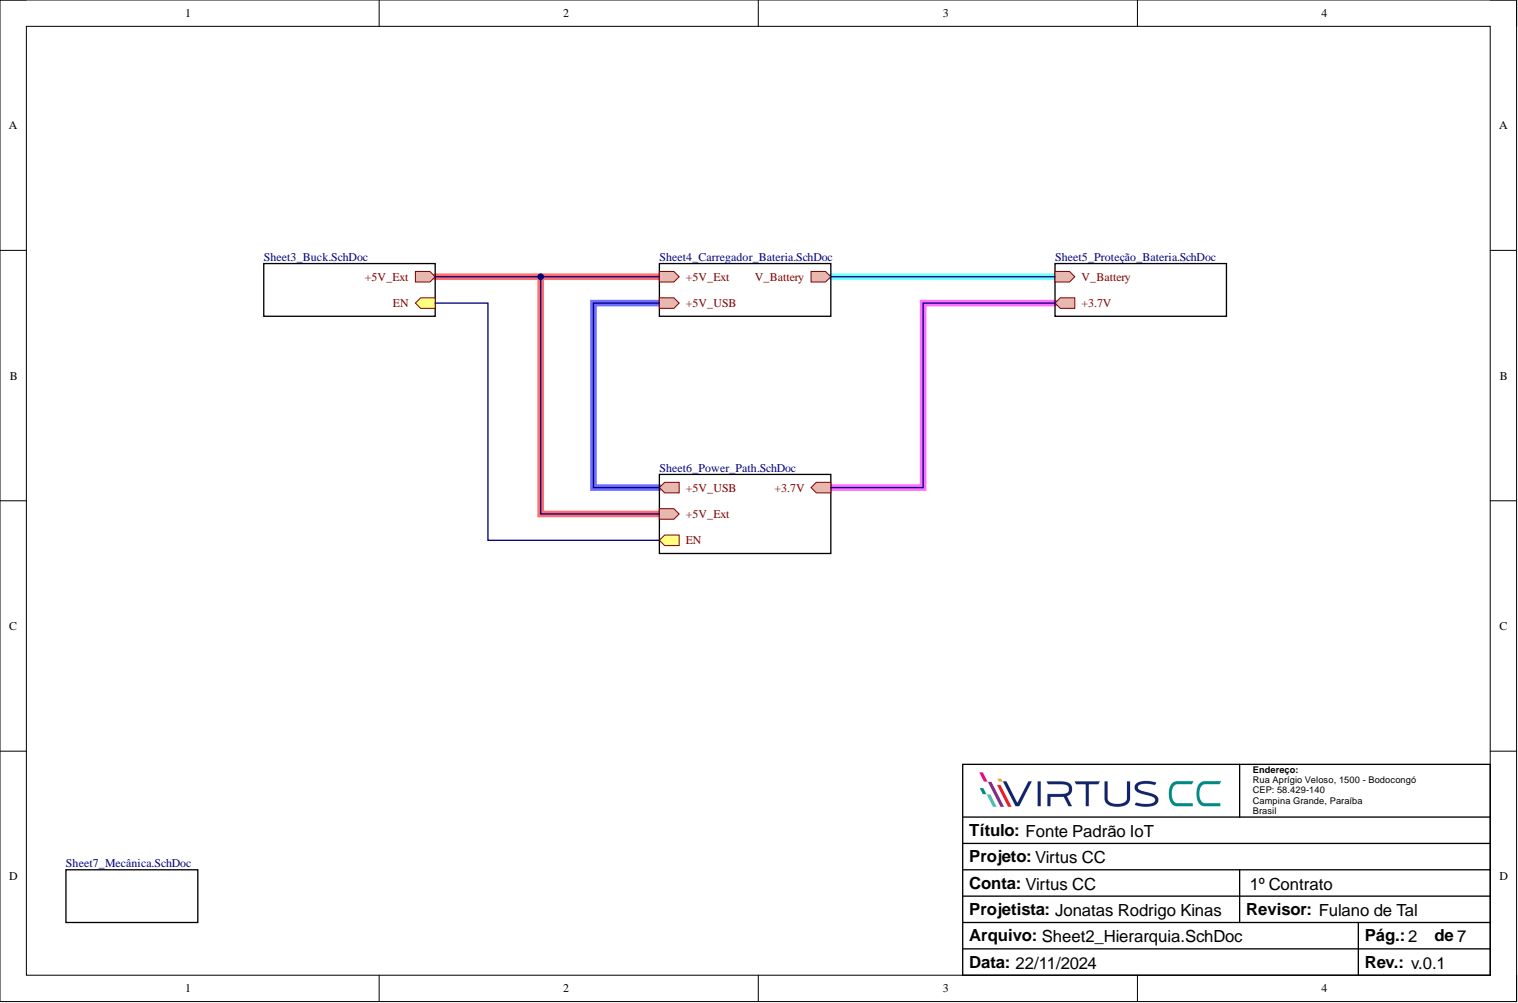
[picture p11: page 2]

Endereço:
Rua Aprígio Veloso, 1500 - Bodocongó
CEP: 58.429-140
Campina Grande, Paraíba
Brasil

Conta: Virtus CC | 1º Contrato
Projetista: Jonatas Rodrigo Kinas | Revisor: Fulano de Tal

Sheet2_Hierarquia.SchDoc | 2 7

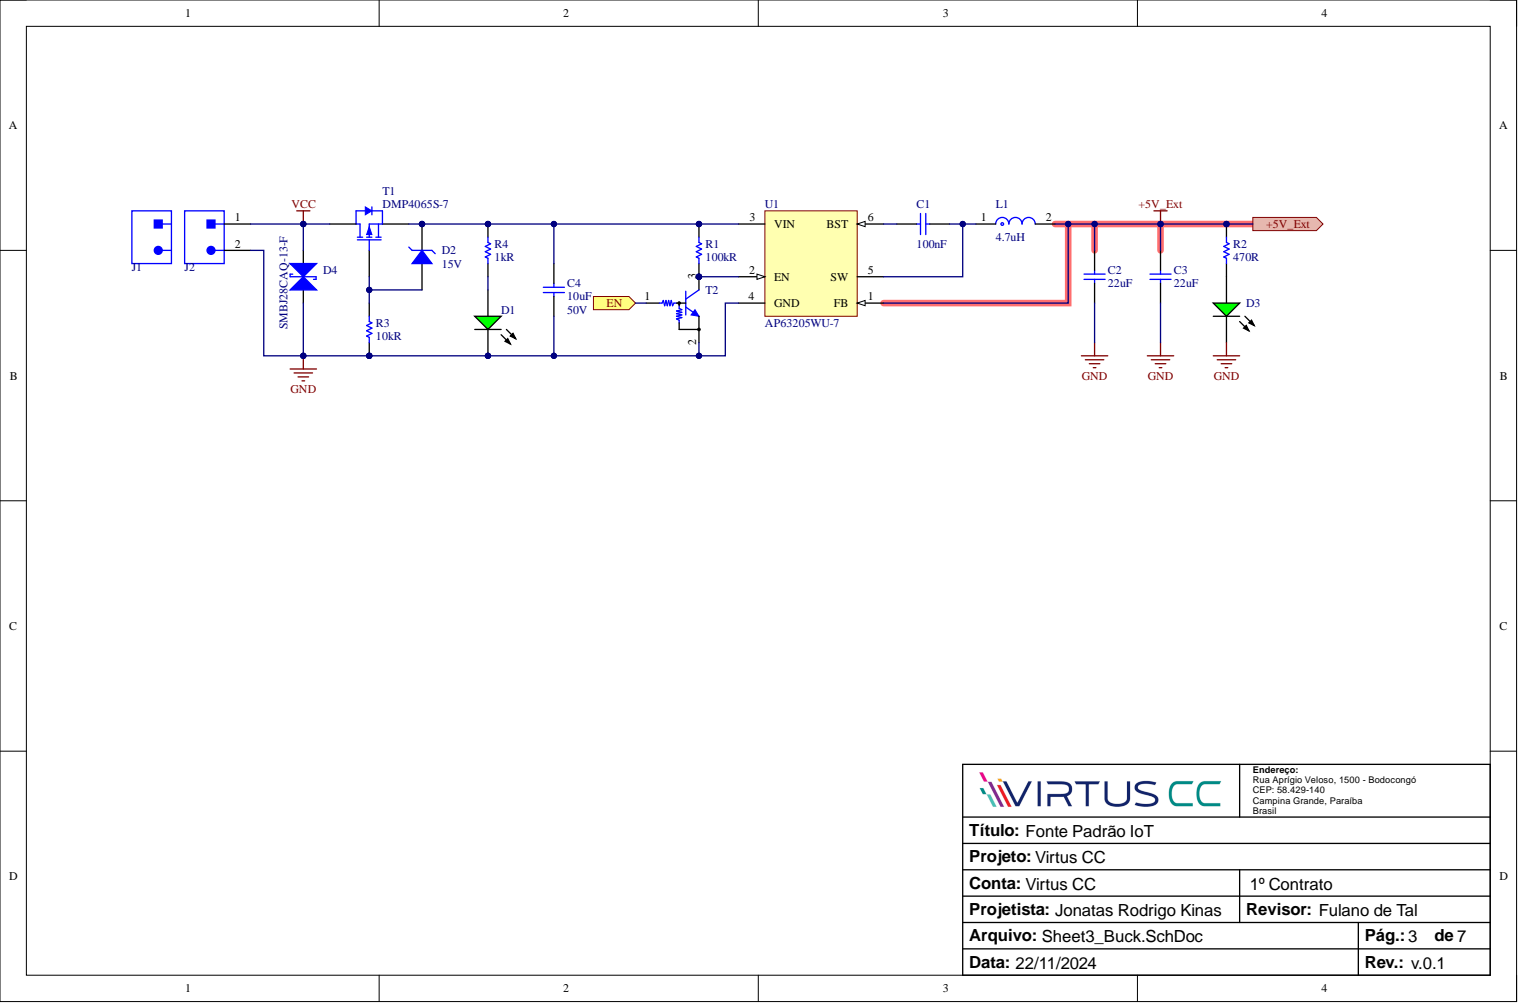
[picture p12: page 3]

Conta : C C V irtus | º Contrat 1 o
Projeti s t a : Jonatas Rodrigo Kinas | Reviso r : Fulano de Tal
Arquivo : Sheet3_Buck.SchD o c | P ág.
Data | Rev . v

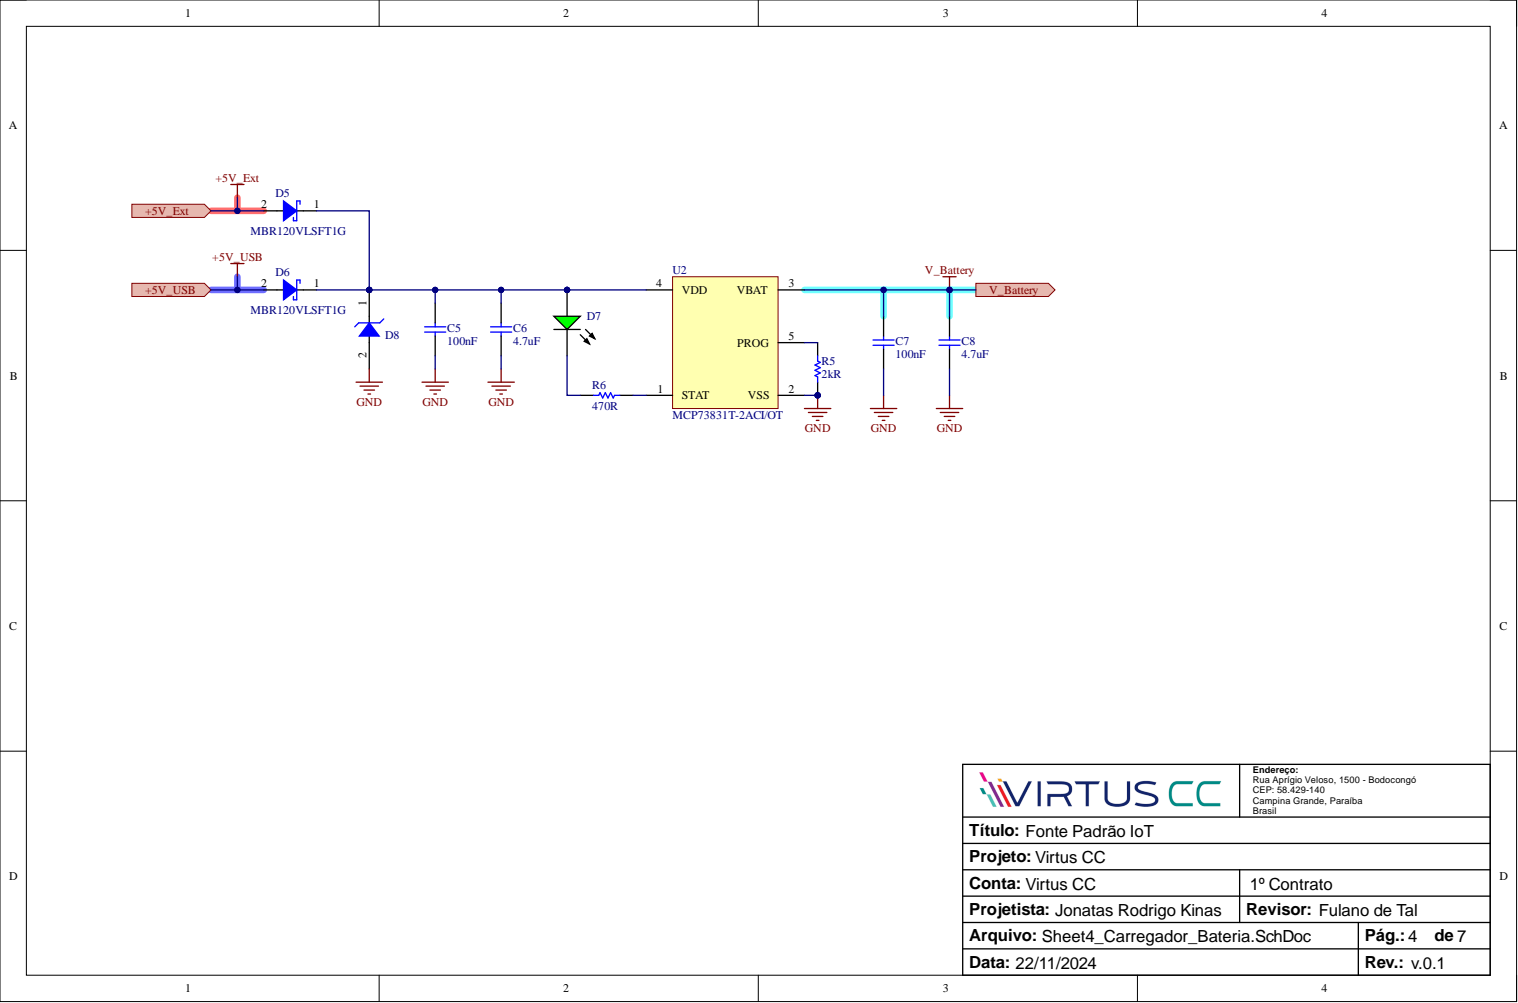
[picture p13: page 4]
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

Sheet4_Carregador_Bateria. S h D

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

Sheet5_Prot eção_Bateria.Sc h D


Endereço:
Rua Aprígio Veloso, 1500 - Bodocongó
CEP: 58.429-140
Campina Grande, Paraíba
Brasil

Conta: Virtus CC | 1º Contrato
Projetista: Jonatas Rodrigo Kinas | Revisor: Fulano de Tal

Sheet6_Power_Path.SchDoc | 6 7


Endereço:
Rua Aprígio Veloso, 1500 - Bodocongó
CEP: 58.429-140
Campina Grande, Paraíba
Brasil

Conta: Virtus CC | 1º Contrato
Projetista: Jonatas Rodrigo Kinas | Revisor: Fulano de Tal

Sheet7_Mecânica.SchDoc | 7 7

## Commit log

2024-10-01 [Prj] Criação do projeto e gitigore
    [PCB_Project_Source_IoT.PrjPcb, Sheet1_Diagrama.SchDoc]
2024-10-01 [Prj] Criação do projeto base
    [PCB_Project_Source_IoT.PrjPcb, PCB_Source_IoT.PcbDoc, Sheet2_Hierarquia.SchDoc]
2024-10-01 [Prj] Add Sheet3
    [PCB_Project_Source_IoT.PrjPcb, Sheet3_Source.SchDoc]
2024-10-01 [Prj] Add Sheet4
    [PCB_Project_Source_IoT.PrjPcb, Sheet4.SchDoc]
2024-10-06 [Prj] Atulização do projeto, Add variant, deleta Sheets 3 e 4 e atuliza gitignore
    [PCB_Project_Source_IoT.PrjPcb, Sheet3_Source.SchDoc, Sheet4.SchDoc]
2024-10-06 [Template] Add Title Block Virtus CC
    [PCB_Project_Source_IoT.PrjPcb, Sheet1_Diagrama.SchDoc, Sheet2_Hierarquia.SchDoc]
2024-10-06 [Template] Criação de Template Schematic Sheet A4, A3 e A2
    [PCB_Project_Source_IoT.PrjPcb, Sheet2_Hierarquia.SchDoc]
2024-10-06 [Prj] Modificaão tamanho PCB
    [PCB_Source_IoT.PcbDoc]
2024-10-10 [Libraries] Criação de Componentes
    [Sheet2_Hierarquia.SchDoc]
2024-10-14 [Esquemáticos] Inclusão do diagrama e criação das sheets 3, 4, 5 e 6
    [PCB_Project_Source_IoT.PrjPcb, Sheet1_Diagrama.SchDoc, Sheet3_Buck.SchDoc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]
2024-10-14 [Esquemático] Finalização esquemático Sheet3_Buck
    [PCB_Project_Source_IoT.PrjPcb, Sheet3_Buck.SchDoc, Sheet4_Carregador_Bateria.SchDoc]
2024-10-15 [Esquemático] Finalização dos esquemáticos
    [Sheet3_Buck.SchDoc, Sheet4_Carregador_Bateria.SchDoc, Sheet5_Proteção_Bateria.SchDoc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]
2024-10-15 [Esquemático] Anotação dos componentes e remoção de erros de compilação
    [PCB_Project_Source_IoT.PrjPcb, Sheet3_Buck.SchDoc, Sheet4_Carregador_Bateria.SchDoc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]
2024-10-15 [Esquemático] Criação da hierarquia de projeto
    [PCB_Project_Source_IoT.PrjPcb, Sheet1_Diagrama.SchDoc, Sheet2_Hierarquia.SchDoc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]
2024-11-05 [Esquemático] Finalização do esquemático
    [PCB_Project_Source_IoT.PrjPcb, PCB_Project_Source_IoT.xlsx, PCB_Source_IoT.PcbDoc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]
2024-11-07 [PCB] Roteamento da placa
    [PCB_Project_Source_IoT.PrjPcb, Sheet3_Buck.SchDoc]
2024-11-07 [PCB] Finalização roteamento
2024-11-08 [PCB][Esquemático] Criação da sheet7 e atualização da PCB
    [PCB_Project_Source_IoT.PrjPcb, Sheet2_Hierarquia.SchDoc, Sheet7_Mecânica.SchDoc]
2024-11-11 [Prj] Finalização projeto
    [Bill of Materials-PCB_Project_Source_IoT.xlsx, PCB_Project_Source_IoT.PrjPcb, PCB_Project_Source_IoT.xlsx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]
